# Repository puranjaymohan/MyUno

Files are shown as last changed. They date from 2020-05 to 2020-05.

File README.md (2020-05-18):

# MyUno
### AVR Atmega 328P based development board. Compatible with Arduino Uno.
### The Schematic and the PCB has been designed using the Altium 20 software. All files related to this design have been uploaded here for your use.

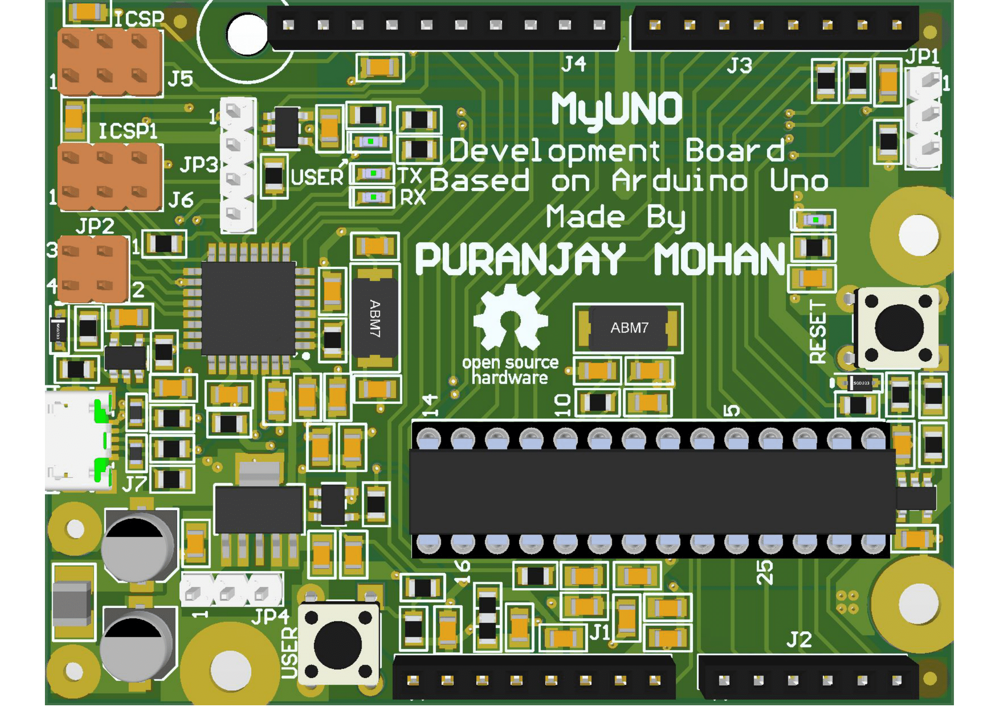
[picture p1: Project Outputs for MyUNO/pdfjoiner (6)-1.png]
Board Top

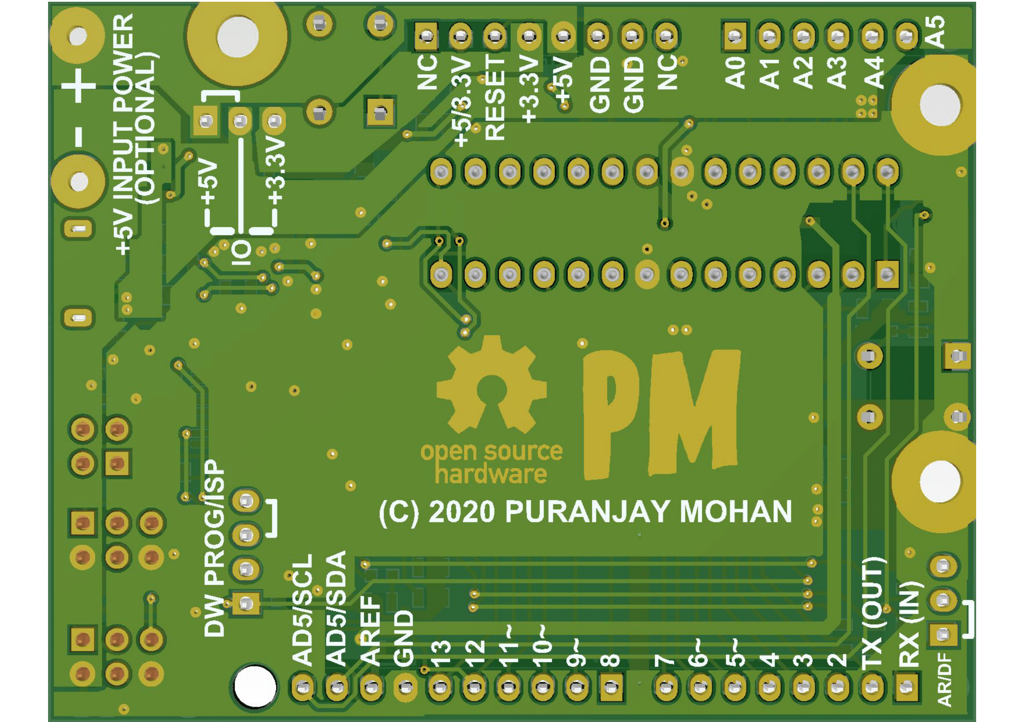
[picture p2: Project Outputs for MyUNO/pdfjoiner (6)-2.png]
Board Bottom

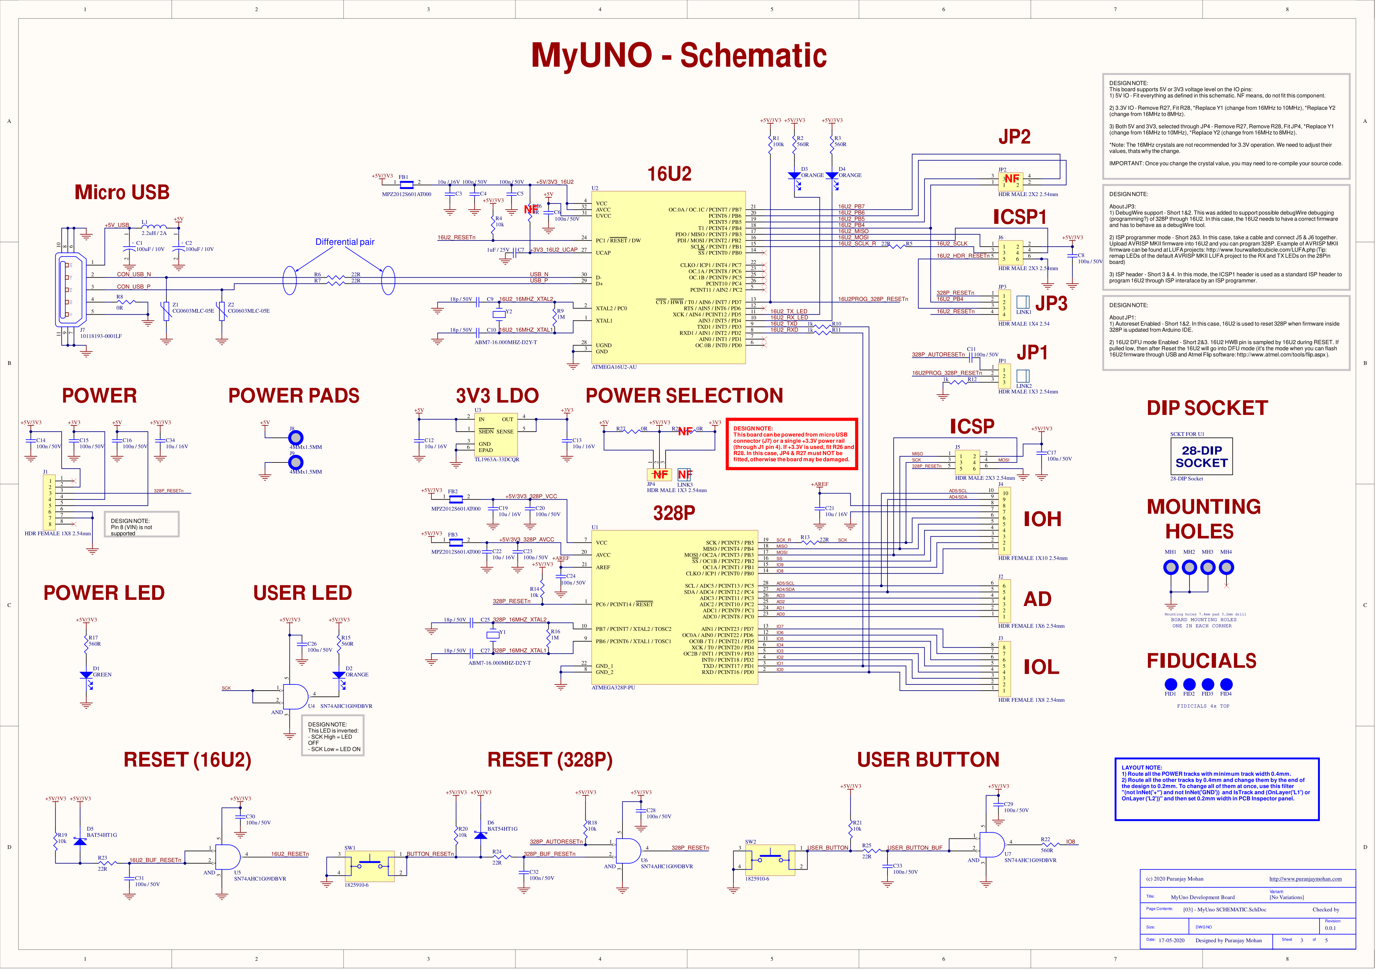
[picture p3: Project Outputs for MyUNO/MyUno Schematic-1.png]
Schematic


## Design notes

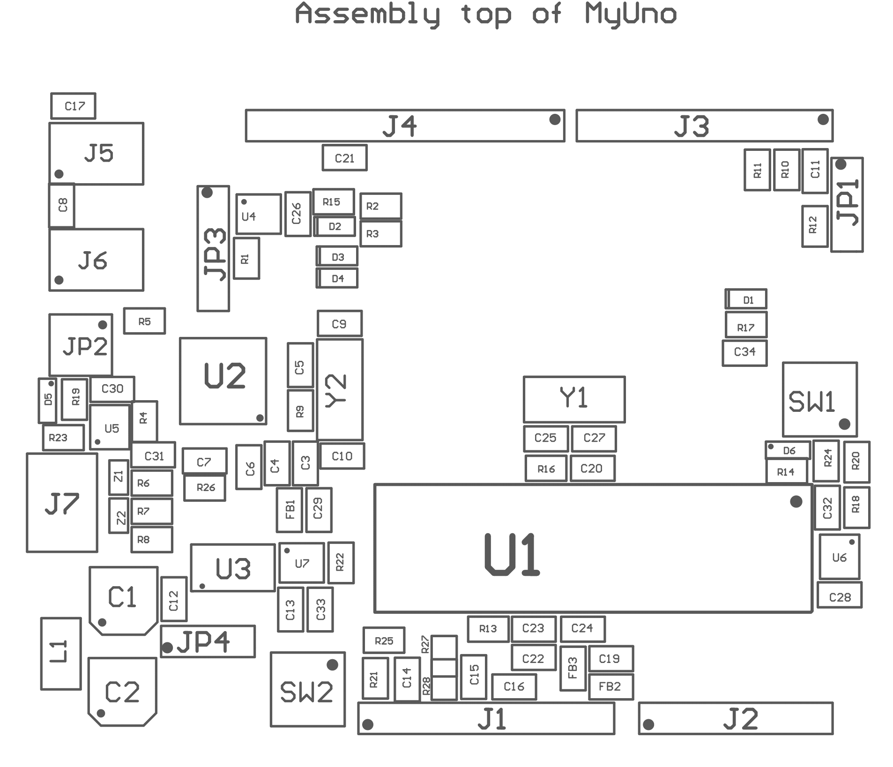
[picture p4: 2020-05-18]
Project Outputs for MyUNO/pdfjoiner (6)-5.png

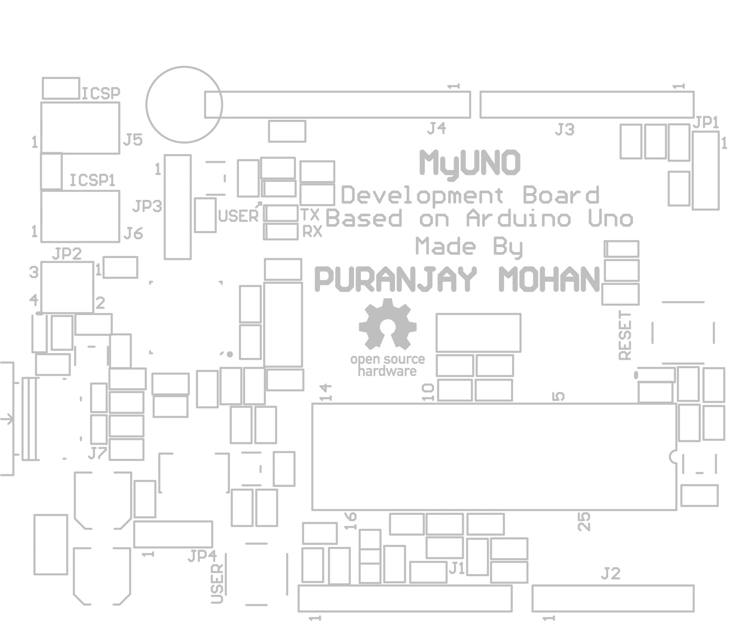
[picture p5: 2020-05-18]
Project Outputs for MyUNO/pdfjoiner (6)-6.png

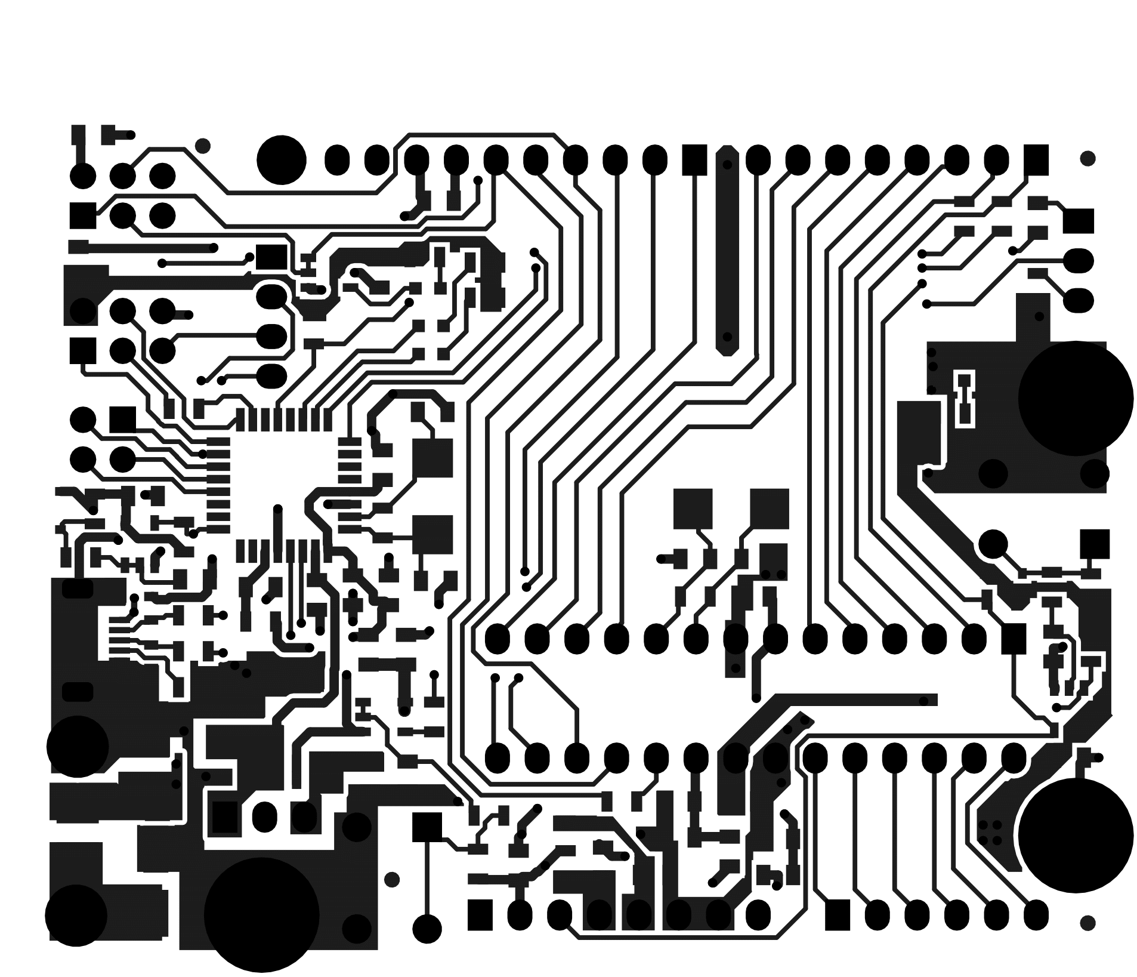
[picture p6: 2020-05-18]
Project Outputs for MyUNO/pdfjoiner (6)-3.png

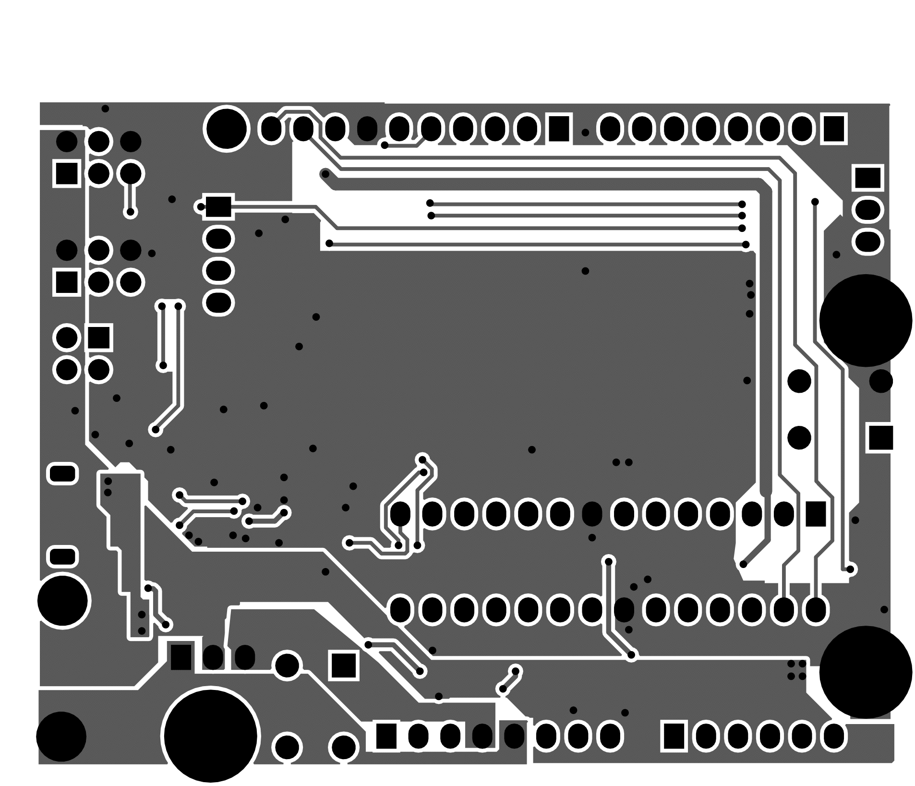
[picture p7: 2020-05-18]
Project Outputs for MyUNO/pdfjoiner (6)-4.png

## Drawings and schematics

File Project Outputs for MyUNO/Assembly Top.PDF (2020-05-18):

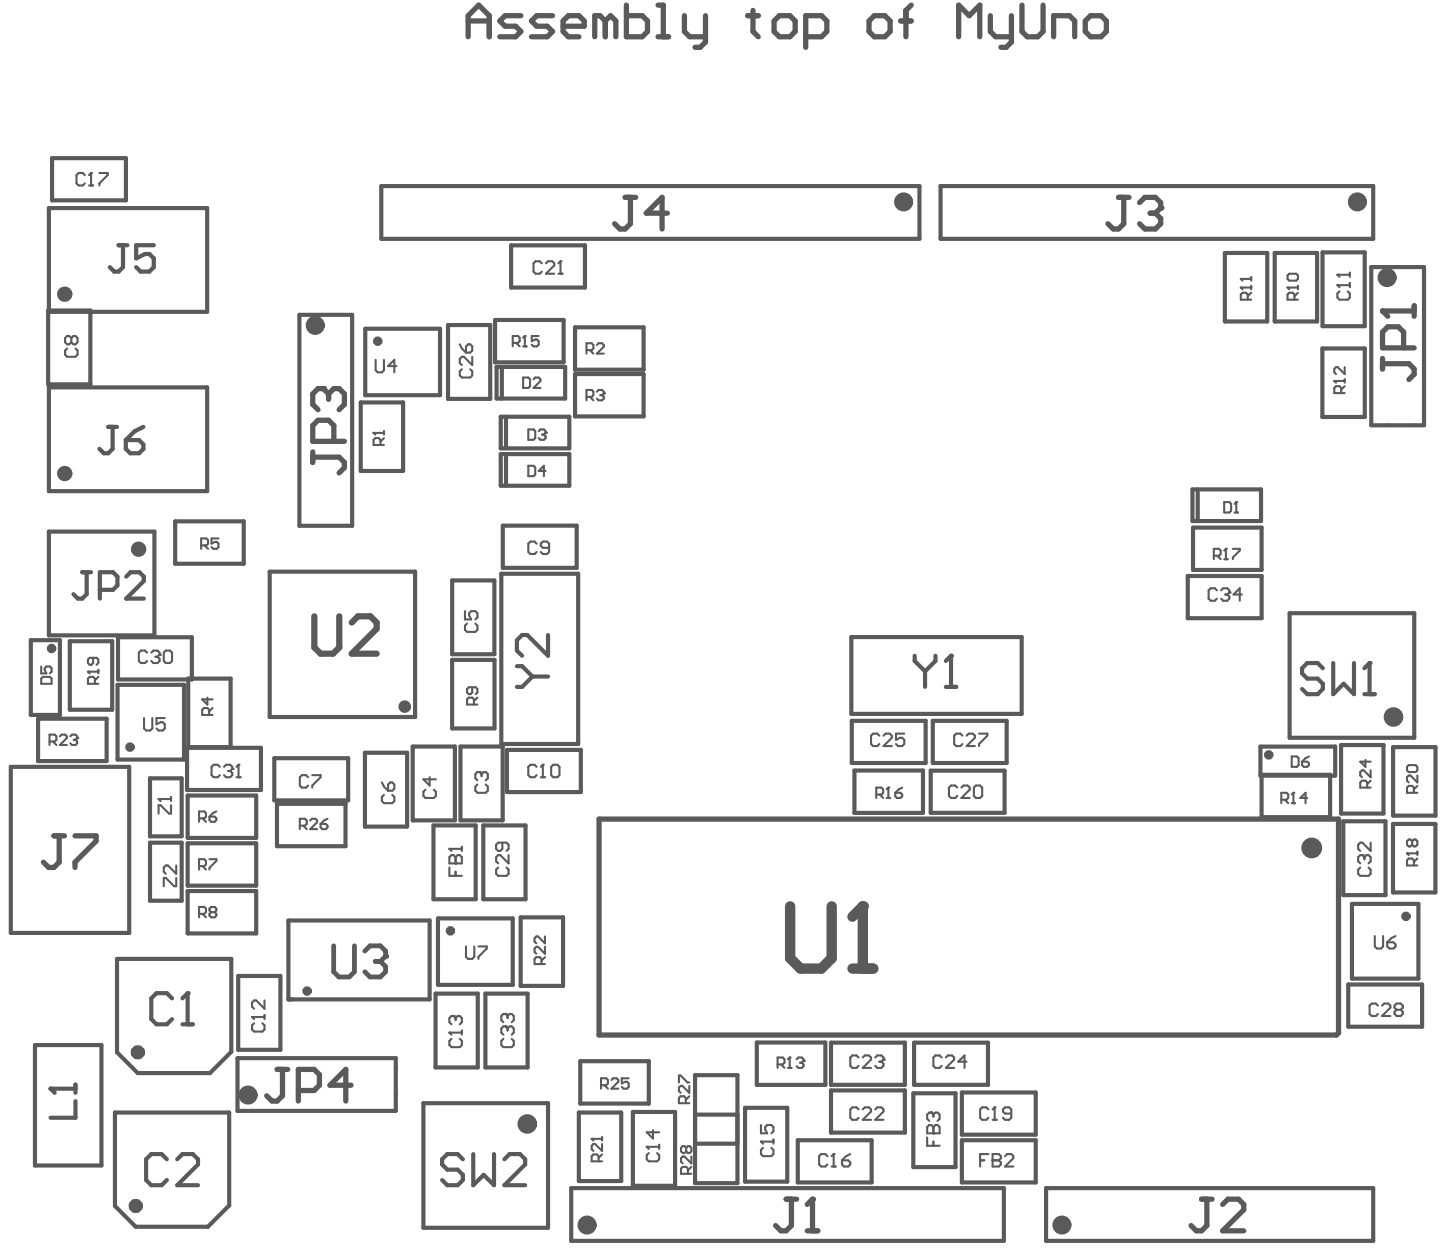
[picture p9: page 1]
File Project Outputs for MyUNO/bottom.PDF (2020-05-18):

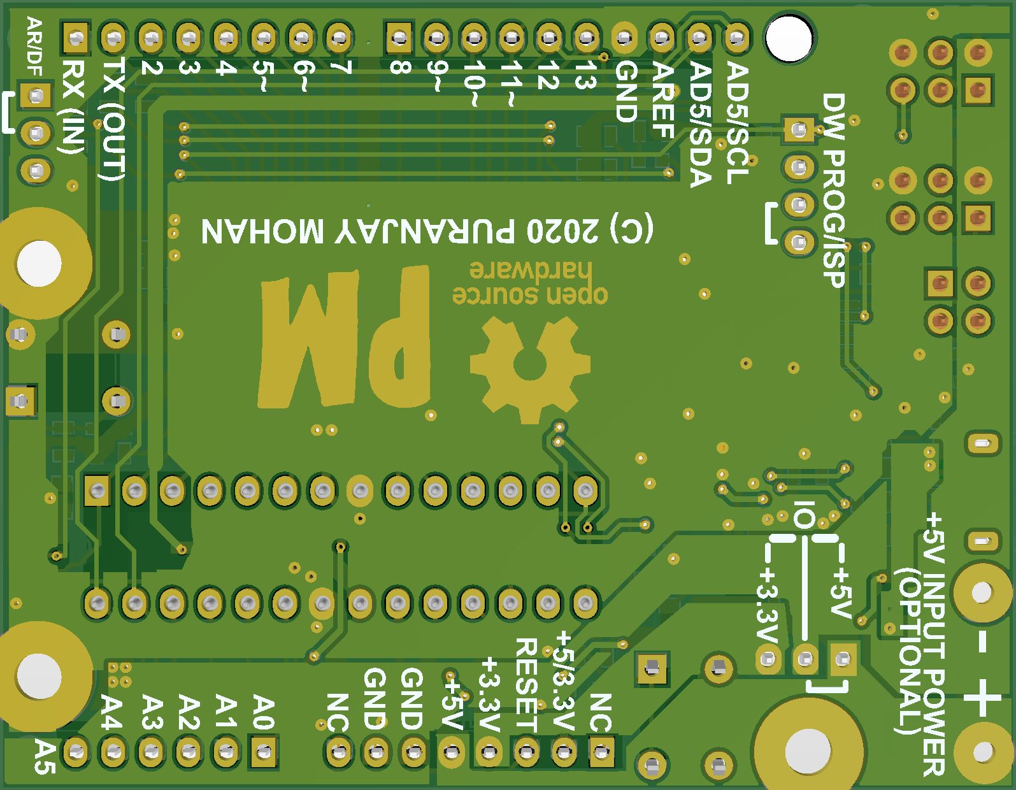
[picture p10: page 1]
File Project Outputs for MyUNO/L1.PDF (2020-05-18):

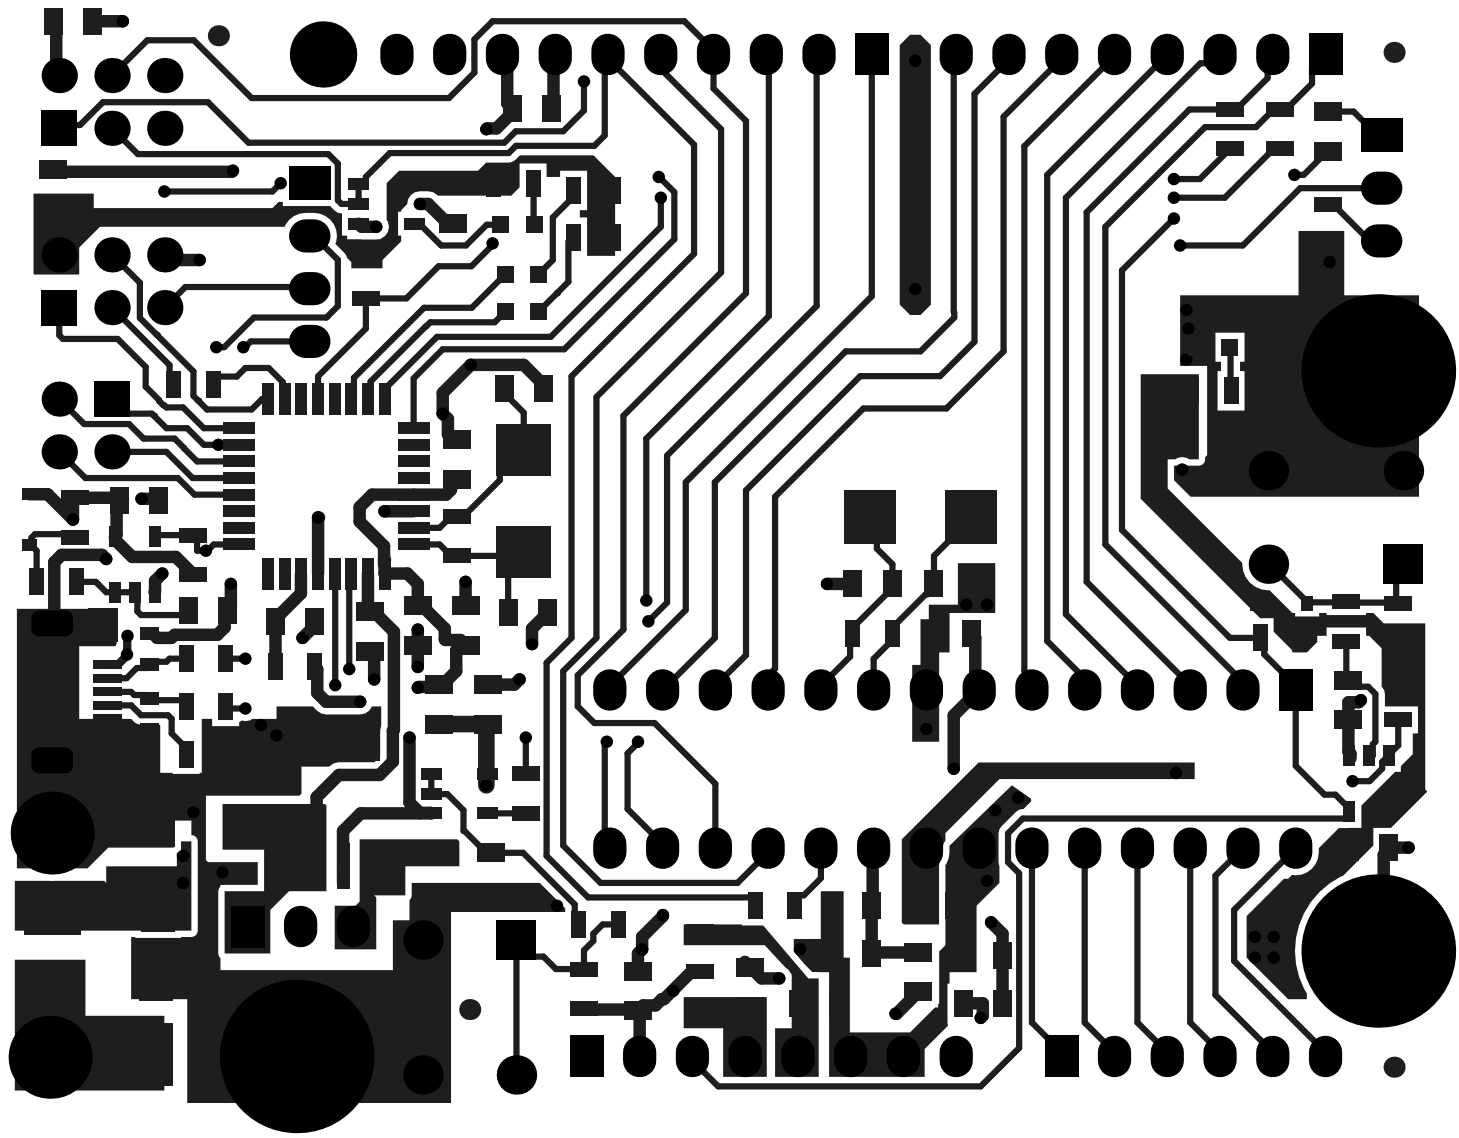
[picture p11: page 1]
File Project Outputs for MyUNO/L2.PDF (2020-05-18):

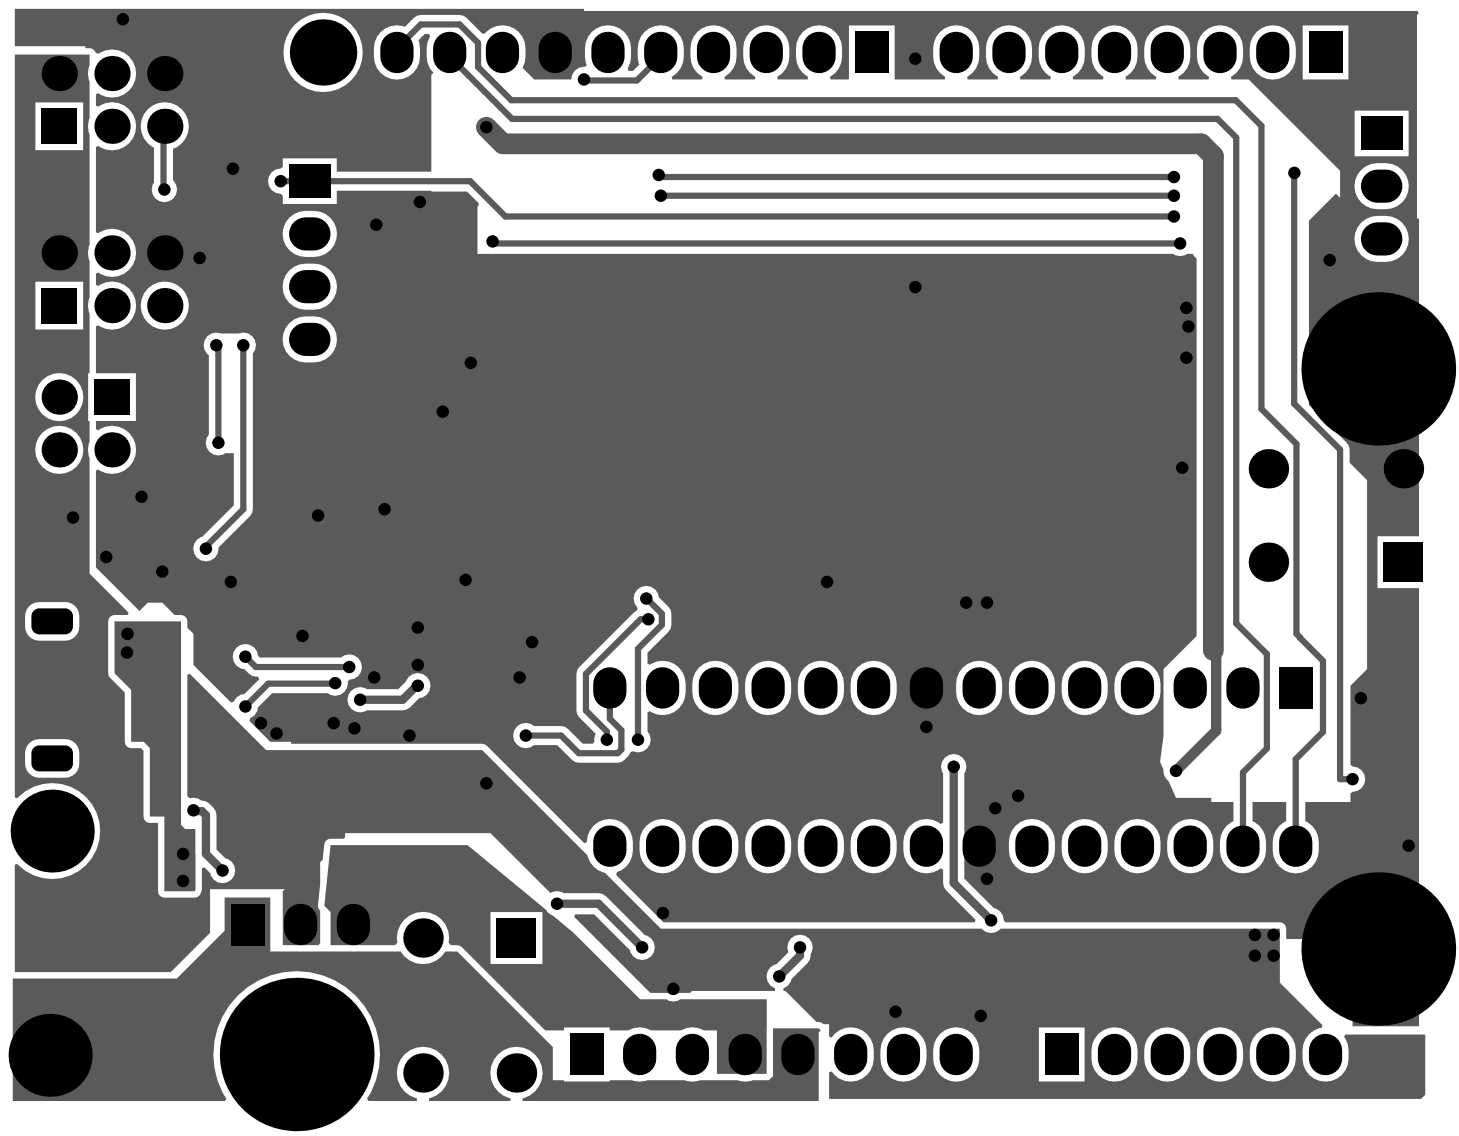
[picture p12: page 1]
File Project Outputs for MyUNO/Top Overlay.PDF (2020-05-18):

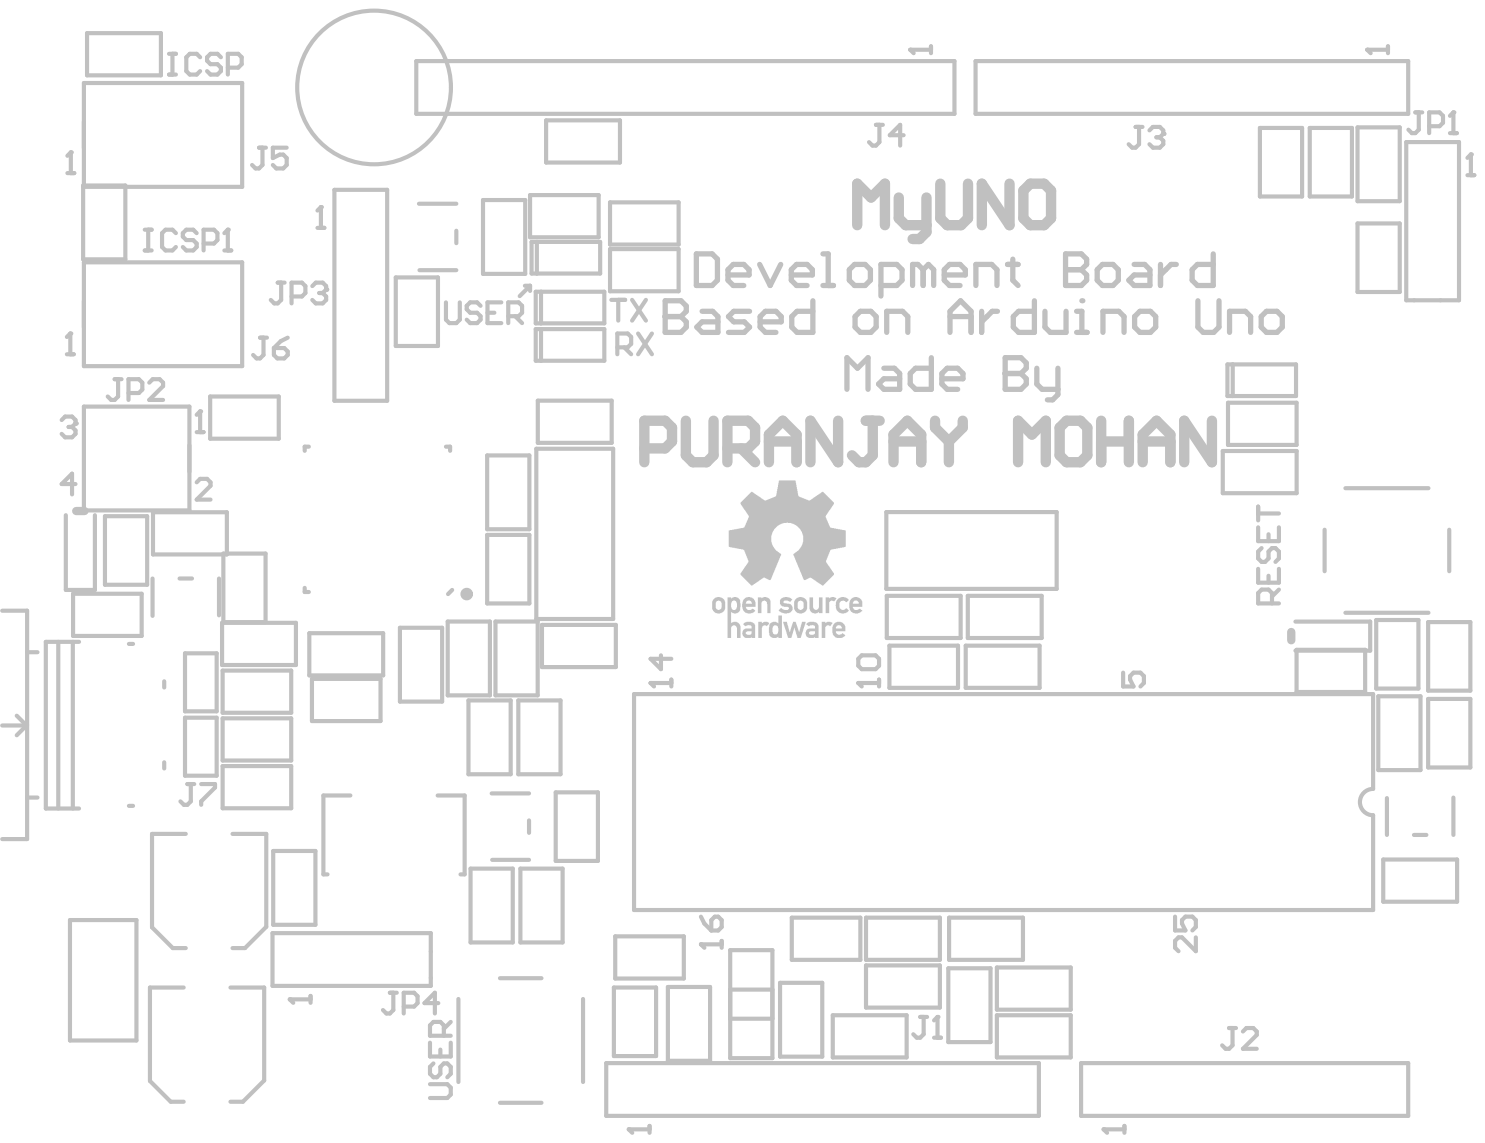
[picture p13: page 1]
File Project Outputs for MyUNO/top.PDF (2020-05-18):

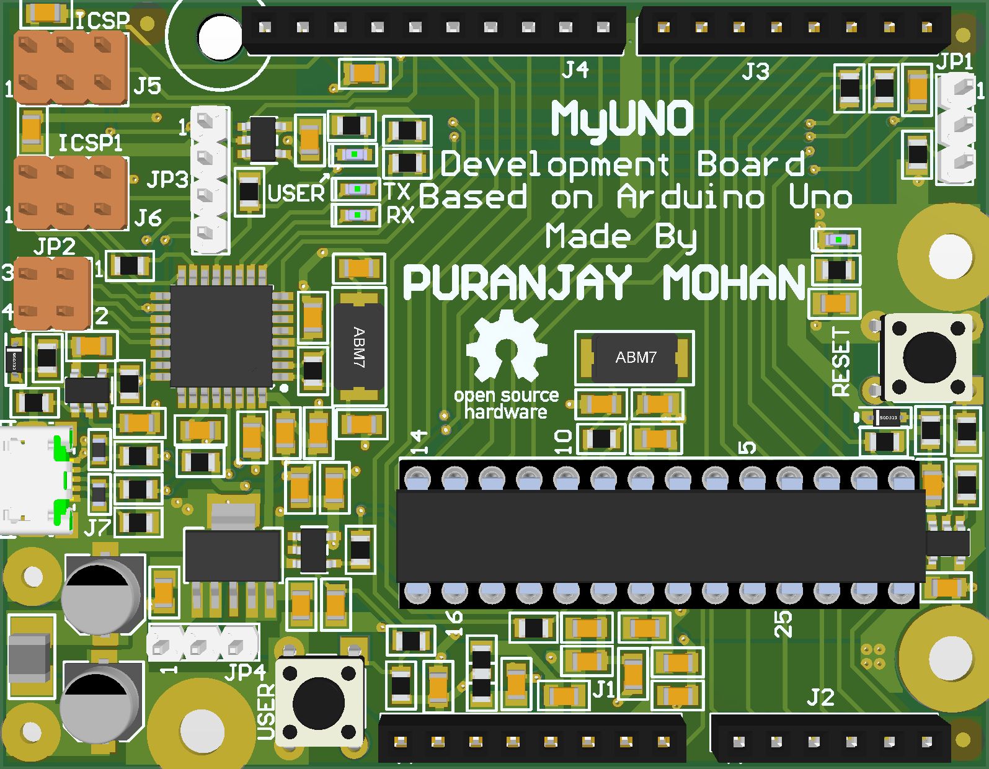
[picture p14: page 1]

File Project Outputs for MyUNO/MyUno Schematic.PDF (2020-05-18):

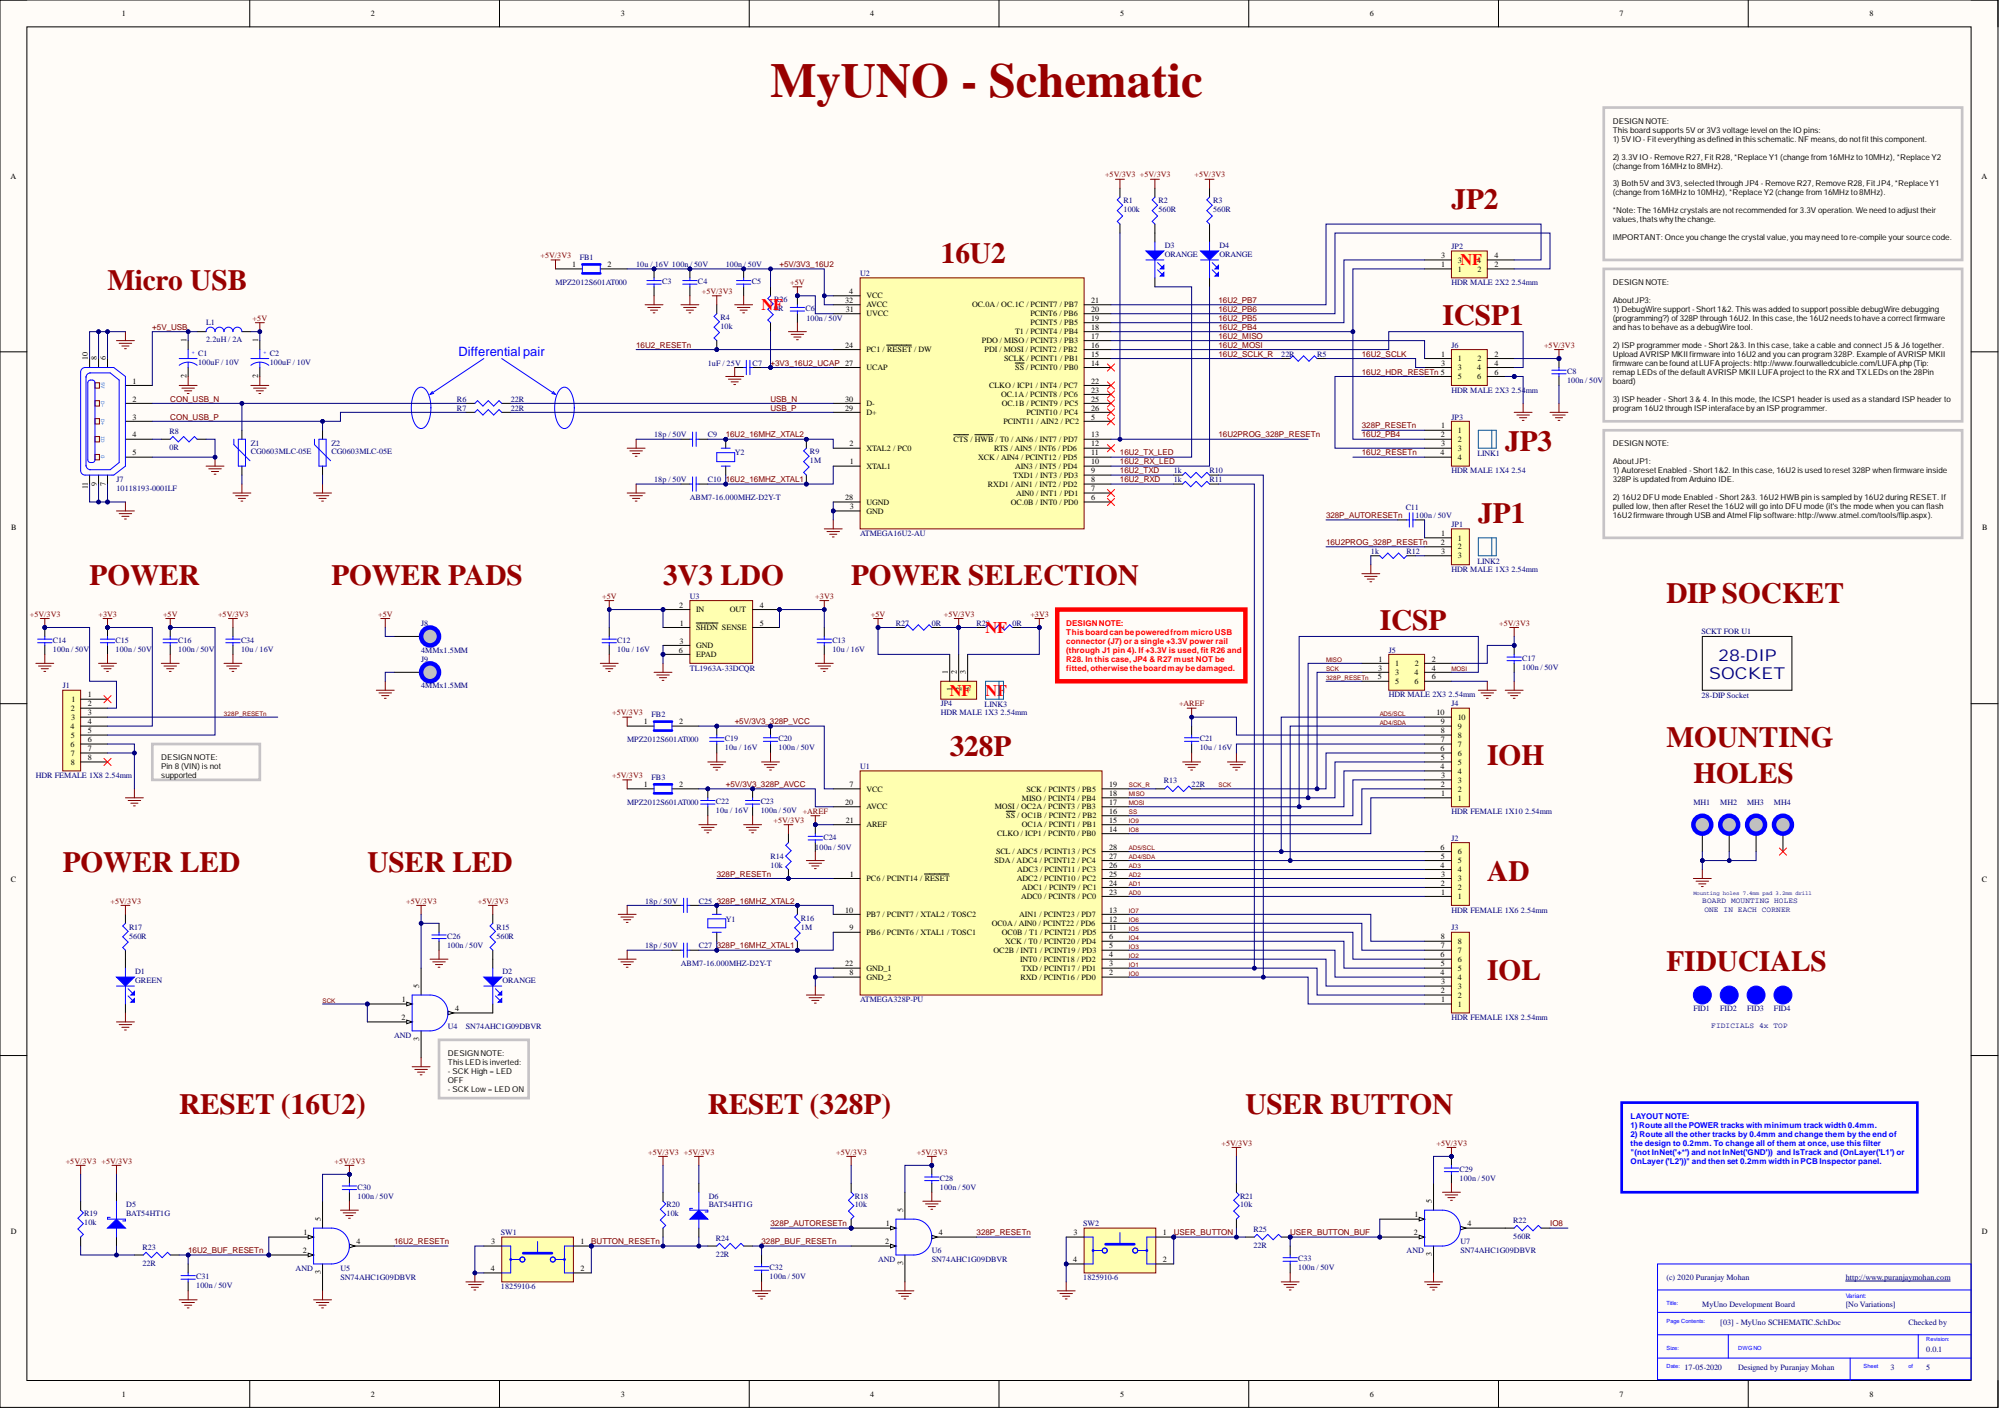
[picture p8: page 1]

DESIGN NOTE:
This board supports 5V or 3V3 voltage level on the IO pins:
1) 5V IO - Fit everything as defined in this schematic. NF means, do not fit this component.

2) 3.3V IO - Remove R27, Fit R28,*Replace Y1 (change from 16MHz to 10MHz), *Replace Y2
(change from 16MHz to 8MHz).

3) Both 5V and 3V3, selected through JP4 - Remove R27, Remove R28, Fit JP4,*Replace Y1
(change from 16MHz to 10MHz), *Replace Y2 (change from 16MHz to 8MHz).

*Note: The 16MHz crystals are not recommended for 3.3V operation. We need to adjust their
values, thats why the change.

IMPORTANT: Once you change the crystal value, you may need to re-compile your source code.

UVCC 31 AVCC 32 | 16U2_PB6

About JP3:
1) DebugWire support - Short 1&2. This was added to support possible debugWire debugging
(programming?) of 328P through 16U2. In this case, the 16U2 needs to have a correct firmware
and has to behave as a debugWire tool.

16U2_PB4
16U2_MISO | | J6
16U2_MOSI

2) ISP programmer mode - Short 2&3. In this case, take a cable and connect J5 & J6 together.
Upload AVRISP MKII firmware into 16U2 and you can program 328P. Example of AVRISP MKII
firmware can be found at LUFA projects: http://www.fourwalledcubicle.com/LUFA.php (Tip:
remap LEDs of the default AVRISP MKII LUFA project to the RX and TX LEDs on the 28Pin
board)

UCAP 27 | | 16U2_SCLK_R 22R R5 | 16U2_SCLK

3) ISP header - Short 3 & 4. In this mode, the ICSP1 header is used as a standard ISP header to
program 16U2 through ISP interaface by an ISP programmer.

About JP1:
1) Autoreset Enabled - Short 1&2. In this case, 16U2 is used to reset 328P when firmware inside
328P is updated from Arduino IDE.

2) 16U2 DFU mode Enabled - Short 2&3. 16U2 HWB pin is sampled by 16U2 during RESET. If
pulled low, then after Reset the 16U2 will go into DFU mode (it's the mode when you can flash
16U2 firmware through USB and Atmel Flip software: http://www.atmel.com/tools/flip.aspx ).

This board can be powered from micro USB
connector (J7) or a single +3.3V power rail
(through J1 pin 4). If +3.3V is used, fit R26 and
R28. In this case, JP4 & R27 must NOT be
fitted, otherwise the board may be damaged.

Pin 8 (VIN) is not
supported

R13 22R SCK_R | SCK

AVCC 20 | MISO

PC6 / PCINT14 / RESET 1 | | IO8

AD5/SCL
AD4/SDA

PB7 / PCINT7 / XTAL2 / TOSC2 10 | AD1

Mounting holes 7.4mm pad 3.2mm drill
BOARD MOUNTING HOLES
ONE IN EACH CORNER
FIDUCIALS

IO7
IO1 | | | 1 1 2 2 3 3 4 4 5 5 6 6 7 7 8 8

GND_1 22 | IO4

GND_2 8 | IO0

This LED is inverted:
- SCK High = LED
OFF
- SCK Low = LED ON

LAYOUT NOTE:
1) Route all the POWER tracks with minimum track width 0.4mm.
2) Route all the other tracks by 0.4mm and change them by the end of
the design to 0.2mm. To change all of them at once, use this filter
"(not InNet('+*') and not InNet('GND')) and IsTrack and (OnLayer('L1') or
OnLayer('L2'))" and then set 0.2mm width in PCB Inspector panel.

http://www.puranjaymohan.com

Size: | DWG NO | Revision: 0.0.1

Date: 17-05-2020 Designed by Puranjay Mohan | Sheet 3 of 5
